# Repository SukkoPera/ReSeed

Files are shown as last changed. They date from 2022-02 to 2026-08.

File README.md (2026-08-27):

# ReSeed





ReSeed is an expansion card for the Commodore 16 and Plus/4 computers that allows interfacing the computer with a [MOS 6581 or 8580 Sound Interface Device](https://en.wikipedia.org/wiki/MOS_Technology_6581), the chip that is used to deliver audio on the Commodore 64.

It is based on [a design by Solder of Synergy](https://plus4world.powweb.com/hardware/Solders_SID_Card).

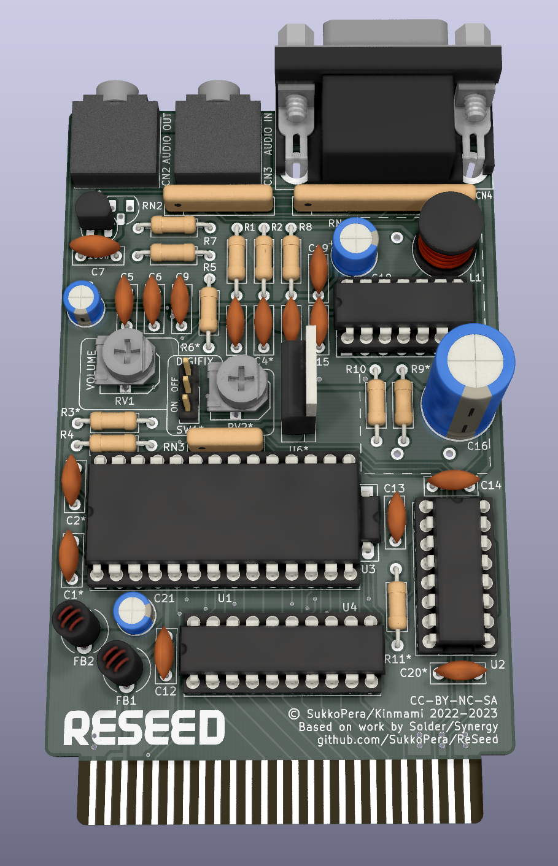
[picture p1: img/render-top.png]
Board


## Summary
Sounds from the C64 now for the Plus/4! Just plug the card into the Expansion Port! You can adjust the volume on the card. You can hear the sound over the Plus/4 audio or take it over a 3.5mm-Stereo-Cinch to a mixer or HiFi-Device. A 9-pin D-SUB connector allows connecting a 3<sup>rd</sup> (analog!) joystick or a proportional-mouse or (why not?) paddles!

*(Slight rewording of Solder's original description of the card.)*

## Design
ReSeed is derived from Solder's SIDcard, with a few enhancements.

### Modifications Introduced in V2
The focus for V2 was on reducing the output noise.

* New component values for the step-up voltage regulator: The values of some components were fine-tuned (again) in order to place the switching frequency of the step-up voltage converter way out of the audio band. These new values can also be retrofitted on a V1 board and will improve things dramatically (See [V1.1](https://github.com/SukkoPera/ReSeed/releases/tag/v1.1)).
* Alternative voltage step-up module: Cheap step-up voltage boost modules can now be used instead of the TL497-based circuit. Such modules, which can be easily sourced from Chinese portals, are much more modern and use a higher switching frequency, resulting in (near-)zero switching-induced noise. Using them also speeds up the assembly process, as many components can be skipped.
* Linear Regulator: If you are really paranoid about switching-induced noise, you can use the above alternatives as a first-stage voltage regulator and then make a second stage through a linear regulator, which should "eat" any remaining noise and provide the SID with very stable power.
* Separate grounds: A separate audio ground plane was introduced and connected to the signal ground plane through a single ferrite bead, preventing noise from spreading from the latter to the former. A second ferrite bead was inserted on the incoming +5V power rail in order to make it cleaner.
* Alternative BJT footprint: An alternative footprint for the output amplifier transistor was added, allowing for the mounting of the 2SC1815 BJT used in the original C64 audio circuit.
* SID clock delay circuit: This allows use of CD74HCT4520B chips in place of the CD4520B.
* Clock divider reset: Makes sure the SID clock always has the correct phase upon startup/reset.
* Short-circuit protection: In the original Solder design, a short-circuit can happen on the joystick port if it is written to. Series resistors were added in order to avoid this situation.

### Modifications Introduced in [V1](https://github.com/SukkoPera/ReSeed/releases/tag/v1)
* Supports both MOS 6581 and 8580 SIDs: this depends on mounting different components though, the board **cannot** be switched "on-the-fly", see [below](#Assembly).
* A volume control for the DigiFix was added and even a switch to completely bypass it.
* The output switch was removed: audio is automatically redirected to the Plus/4's EXT_AUDIO when nothing is connected to the output jack.
* The second stage of the amplifier was removed and the first stage modified so that it uses the same circuit and component values as the C64: the original card was known to introduce some distortion to the output signal as it was trying to amplify it, these days you can easily do better amplification outboard, so we chose to preserve sound fidelity.
* A decoupling capacitor was added close to every IC.
* The values for the step-up converter were recalculated in order to make the generated voltage less noisy and as ripple-free as possible.
* Last but not least, the design was documented and made open.

## Assembly
If you want to assemble a card, **please read the assembly notes on [the Wiki](https://github.com/SukkoPera/ReSeed/wiki) carefully or you might destroy your SID chip!**

### SID Replacements
Most SID replacements will not work correctly. This is because for technical reasons the clock that is provided to the SID has a lower frequency than what it gets on the C64 (~886 vs ~985 kHz). Most SID replacements do not use this clock signal at all and just assume C64 frequency (I guess), leading to incorrect data transfers. This is the case for the SwinSID firmware, for instance.  See below for a table of tested SID replacement devices.

| SID Device | Compatibility | Source | Notes |
|:---:|:---:|:---:|:---|
| [ARMSID](https://www.nobomi.cz/8bit/armsid/index_en.php) | Yes | [Root42](https://www.youtube.com/watch?v=OQfjMYeEfFY) | May have subtle incompatibility (detected during porting of config tool to +4), but unlikely to be seen in practise. |
| [SIDKick](https://github.com/frntc/SIDKick-pico) | In Progress | [SIDKick Pico Github](https://github.com/frntc/SIDKick-pico/discussions/36) | |
| [SwinSID](https://github.com/dmantione/swinsid) | No | SukkoPera | One report of compatibility, but no evidence provided. |
| BackSID | No | [BackBit Forums](https://forum.backbit.io/index.php?topic=1089.0) | Discontinued closed-source product; firmware unlikely to be patched. |
| [KungFuSID](https://github.com/Sgw32/KungFuSID) | No | SukkoPera |  |
| [PD-SID](https://uni64.com/shop/index.php?system=4&m=70&item_id=7536) | No | SteveGuidi | Firmware v191; no sound output and USB port inhibits proper seating in socket (obstructed by socketed CD74HCT4520E). |

## Games & Software
You can get images of the disks Solder used to ship with his SIDcard [here](https://plus4world.powweb.com/software/Synergy_Sidcard_Software). These will help making sure that the card works as intended.

[Here is also a list](https://plus4world.powweb.com/effects/SID_Support) of a lot of C16/+4 games and software supporting the card.

## Releases
If you want to get this board produced, you are recommended to get [the latest release](https://github.com/SukkoPera/ReSeed/releases) rather than the current git version, as the latter might be under development and is not guaranteed to be working.

Every release is accompanied by its Bill Of Materials (BOM) file and any relevant notes about it, which you are recommended to read carefully.

## Enclosure
A 3D-printable enclosure is currently available for this board, it was kindly contributed by [Starquake](https://www.forum64.de/wcf/index.php?user/17096-starquake/) and it is available in the [enclosure](./enclosure) folder.

Usage should be self-explanatory, just note that there are two slightly different versions depending on the SID model, as the one for the 8580 has an extra hole in the upper shell for the Digifix). You will probably have to bend the ferrites and capacitor at the bottom of the board a little to the side.

2x countersunk head screws M3x5mm will be required for assembly.

Please see [this thread on Forum64](https://www.forum64.de/index.php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) for more information and printing recommendations.

[SteveGuidi](https://github.com/SteveGuidi) kindly contributed original-264-style labels for the completed cartridge.

## License
The ReSeed documentation, including the design itself, is copyright &copy; SukkoPera 2022-2023 and is licensed under the [Creative Commons Attribution-NonCommercial-ShareAlike 4.0 International License](https://creativecommons.org/licenses/by-nc-sa/4.0/).

This documentation is distributed *as is* and WITHOUT ANY EXPRESS OR IMPLIED WARRANTIES whatsoever with respect to its functionality, operability or use, including, without limitation, any implied warranties OF MERCHANTABILITY, SATISFACTORY QUALITY, FITNESS FOR A PARTICULAR PURPOSE or infringement. We expressly disclaim any liability whatsoever for any direct, indirect, consequential, incidental or special damages, including, without limitation, lost revenues, lost profits, losses resulting from business interruption or loss of data, regardless of the form of action or legal theory under which the liability may be asserted, even if advised of the possibility or likelihood of such damages.

## Support the Project
If you want to get some boards manufactured, you can get them from PCBWay through this link:

PCB from PCBWay (https://www.pcbway.com/project/shareproject/ReSeed_v2_SIDcard_for_the_Commodore_16_Plus_4_32f442ec.html)

You get my gratitude and cheap, professionally-made and good quality PCBs, I get some credit that will help with this and [other projects](https://www.pcbway.com/project/member/shareproject/?bmbid=41100). You won't even have to worry about the various PCB options, it's all pre-configured for you!

Also, if you still have to register, [you can use this link](https://www.pcbway.com/setinvite.aspx?inviteid=41100) to get some bonus initial credit (and yield me some more).

You can also buy me a coffee if you want:



## Thanks
- Solder, for designing the original card and sharing its schematics.
- [Kinmami](https://github.com/kinmami) for his invaluable support
- Luca, Chronos and all the folks at [Plus/4 World](https://plus4world.powweb.com/forum) for helping with the troubleshooting
- [thireo](https://github.com/thireo) for the [3D model of the headphone jack](https://github.com/thireo/kicad-library)

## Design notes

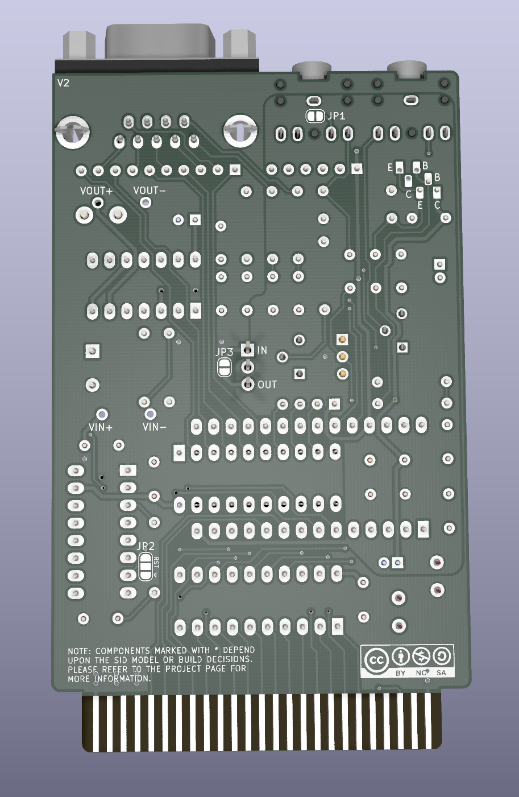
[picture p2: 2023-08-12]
img/render-bottom.png

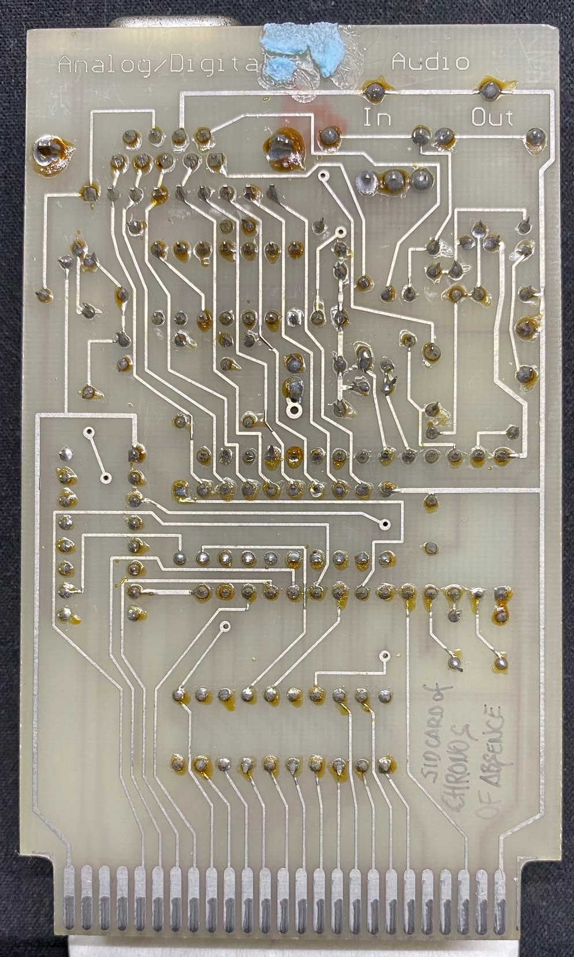
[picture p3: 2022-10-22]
doc/sidcard_chronos_bottom.jpg

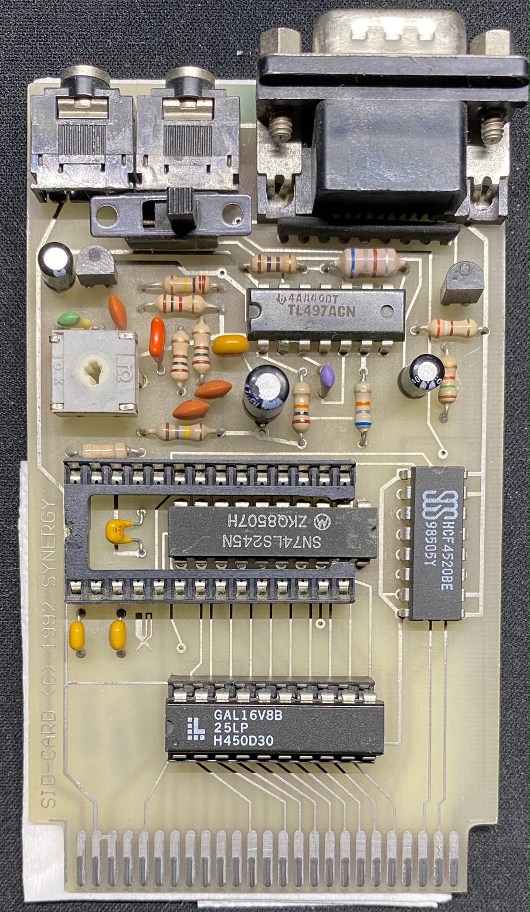
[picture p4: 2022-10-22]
doc/sidcard_chronos_top.jpg

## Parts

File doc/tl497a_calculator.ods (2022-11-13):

Pre-Regulator |  |  |  |  |  |  | Post-Regulator
 | IOMAX (A) | VO Pre (V) | VIN (V) | ton (µs) | Vripple(PK) Vpp | R2 (KΩ) |  | VO Post (V) | Power (W)
TL497A | 0.089 | 14.0 | 5.0 | 11 | 0.003 | 1.2 | 7809 (https://tinyurl.com/4sb5duz7) | 9.0 | 0.5 | No heatsink needed <1W
 |  | 13.9 |  |  | 1mVpp | 1.2 | 7812 (https://tinyurl.com/252ks9af) | 12.0 | 0.2 | No heatsink needed <1W
 | IPK (A) | L (µH) | CT (pF) | R1 (KΩ) | RCL (Ω) | CO Pre (µF)
 | 0.499 | 110.2292769 | 132 | 12.8 | 4.700 | 980.1
 |  | 100 | 130 | 12.7 | 4.7 | 1000
 |  |  |  | f (KHz) | Power (W) | Rated voltage (V)
 |  |  |  | 45.45454545 | 1.17 | 20.85
 |  |  |  |  |  |  |  |  |  | Pre-Regulator VI requires additional coupling capacitors:
 |  |  |  |  |  |  |  |  |  | 0.1µF ceramic
 |  |  |  |  |  |  |  |  |  | 100µF / 16V electrolytic
 |  |  |  |  |  |  |  |  |  | R1 and R2 are ±1%
 |  |  |  |  |  |  |  |  |  | CO Pre - Post are rated for 25V

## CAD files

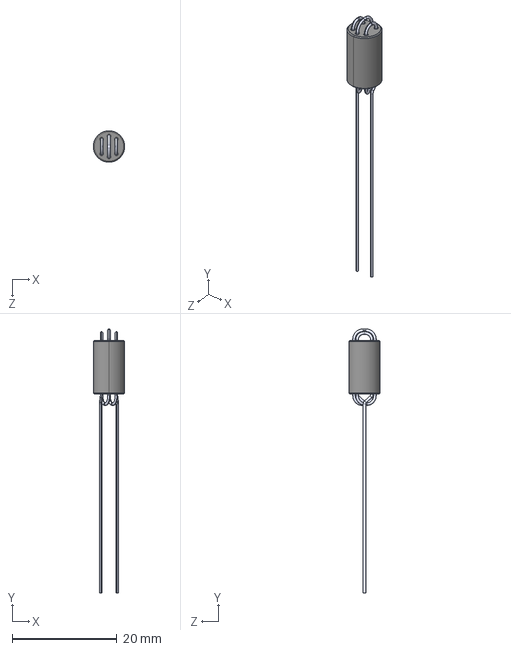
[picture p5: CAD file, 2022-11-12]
3dModels/28C0236-0EW-10--3DModel-STEP-460648.STEP
6.00 x 50.5 x 6.00 mm

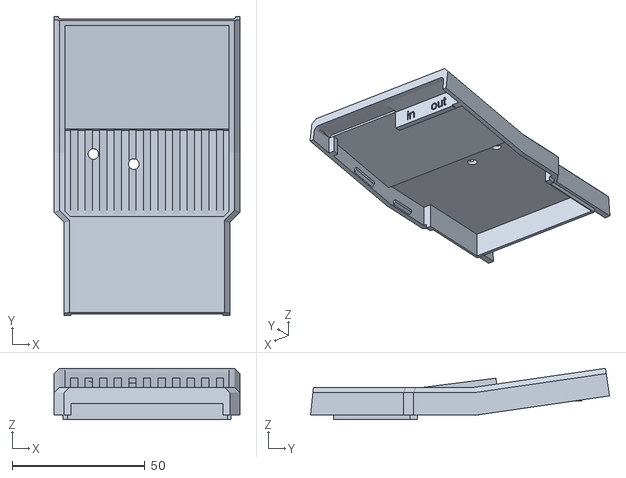
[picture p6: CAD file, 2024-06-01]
enclosure/ReSeed Case Lid 8580.stl
70.0 x 112.8 x 19.4

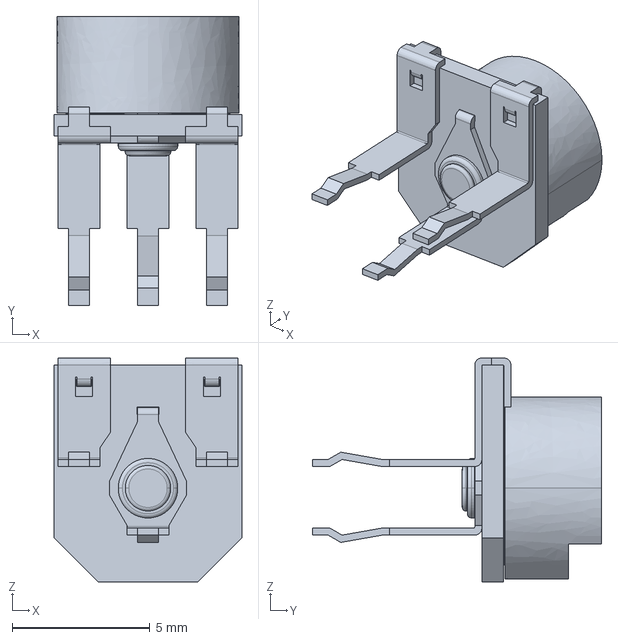
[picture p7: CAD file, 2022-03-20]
3dModels/3306p-1-101.stp
6.81 x 10.5 x 8.13 mm

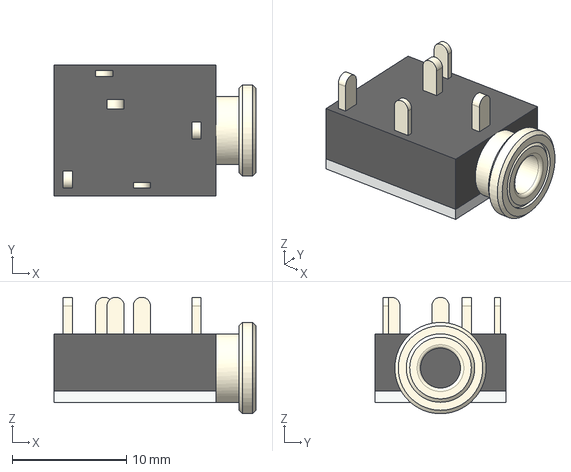
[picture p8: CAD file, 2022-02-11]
3dModels/EBS35 3.5mm Stereo Connector.stp
17.7 x 11.5 x 10.2 mm

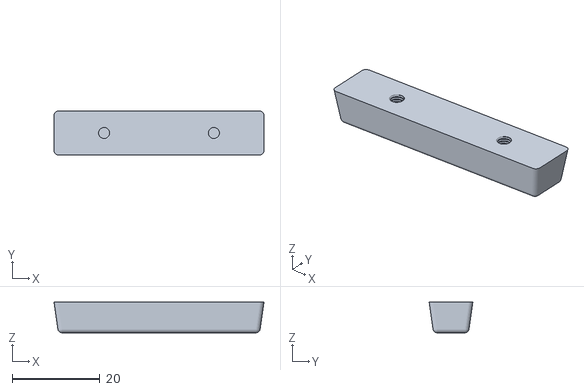
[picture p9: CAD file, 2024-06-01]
enclosure/ReSeed Case Base Spacer.stl
47.8 x 9.98 x 7.00

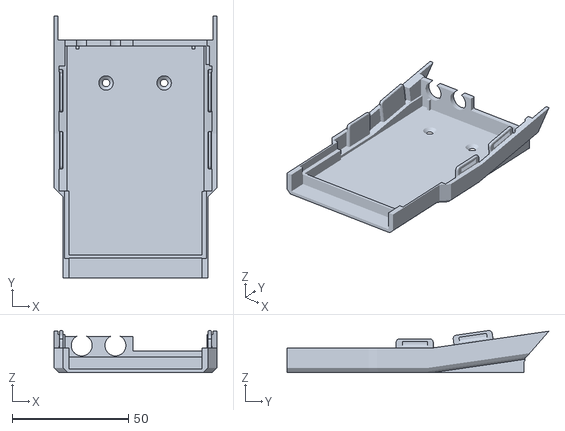
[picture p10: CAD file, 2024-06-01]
enclosure/ReSeed Case Base.stl
70.0 x 112.8 x 18.1

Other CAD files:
enclosure/ReSeed Case Lid 6581 straith.stl
enclosure/ReSeed Case Lid 6581.stl
enclosure/ReSeed Case Lid 8580 straith.stl

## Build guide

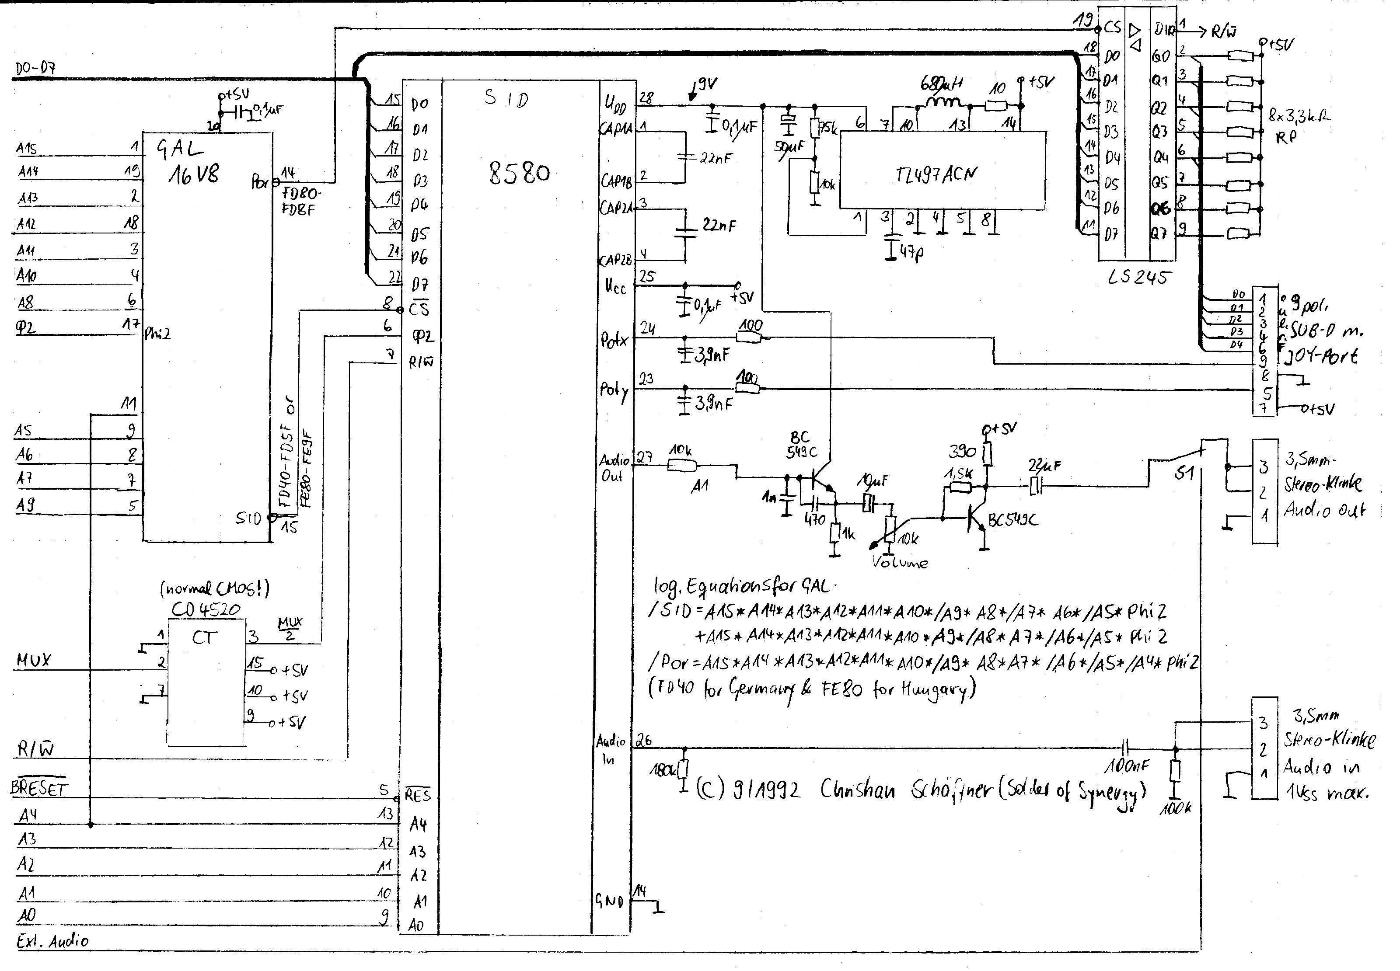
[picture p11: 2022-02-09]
doc/solders_sidcard.gif

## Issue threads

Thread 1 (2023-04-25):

Discrepancies within the generated BOM

kotbehemot53, 2023-04-25:
Hello,
I noticed that there are some discrepancies in the generated BOM, between the Mouser product numbers and corresponding component values:

L1: 652-RLB0914-331KL - the code refers to a 330 uH inductor, yet the component value is 100 uH, which would be 652-RLB0914-101KL;

C15: 810-FG28C0G1H470JNT0 - the code refers to a 47pF capacitor, yet the component value is 100pF which would be 810-FG28C0G1H101JNT6;

Q1: 512-BC549CTA - the code refers to a BC549C BJT transistor, yet the component value is a BC547C BJT which would be 512-BC547CBU;

RN1: 652-4609X-1LF-4.7K - the code refers to a 4.7 kOhm resistor array, yet the component value is 3.3 kOhm, which would be 652-4609X-1LF-3.3K.

I am aware that some of these are interchangeable, but I still think that the product numbers given should match the component values in the table, because in its current state it causes confusion when ordering parts by their numbers and checking their values.

SukkoPera, 2023-04-25:
Thanks for the notice, this will be fixed soon with the release of V1.2 and V2.0.

root42, 2023-08-11:
Any idea when 2.0 will be released? Or can I use the git version? I want to order a minimal number of boards so I can build 1 or 2 SID cards for my C16 and Plus/4 and ask on Forum64 if anyone else wants a board. Or in other words: is it worth waiting for 2.0?

SukkoPera, 2023-08-11:
I just need to find the time to prepare the docs and do the proper release, but the PCB you can find on the _devel_ branch is final. I will try in the weekend.

SukkoPera, 2023-08-12:
[V2](https://github.com/SukkoPera/ReSeed/releases/tag/v2) has been released, this should fix all of the inconsistencies.

I have decided not to make a v1.2, so I put a link to this issue in the v1.1 release. Let me precise that:

> L1: 652-RLB0914-331KL - the code refers to a 330 uH inductor, yet the component value is 100 uH, which would be 652-RLB0914-101KL;

Correct value is 100 uH.

> C15: 810-FG28C0G1H470JNT0 - the code refers to a 47pF capacitor, yet the component value is 100pF which would be 810-FG28C0G1H101JNT6;

Correct value is 100 pF.

> Q1: 512-BC549CTA - the code refers to a BC549C BJT transistor, yet the component value is a BC547C BJT which would be 512-BC547CBU;

Both can be used. BC549C is recommended as it is the low-noise version, but 547 (and 548, for the record) will work, too.

> RN1: 652-4609X-1LF-4.7K - the code refers to a 4.7 kOhm resistor array, yet the component value is 3.3 kOhm, which would be 652-4609X-1LF-3.3K.

Both will work. I recommend 4.7k because it's the value I tested but no worries ;).

@root42 If you want my boards, send me an email. They are gold-plated and beveled.

Closed 2023-08-12.

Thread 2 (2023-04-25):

Expanding the readme with information on how to prepare the GAL chip

kotbehemot53, 2023-04-25:
While building my ReSeed, I noticed that there was no info about what the GAL chip is and that it needs to be programmed before use. It might be obvious to some people, but not necessarily to every hobbyist. Therefore, I suggest adding a paragraph in the readme with some basic information.

I wanted to create my own branch and make a PR, but I didn't have sufficient permissions, so I'll paste my suggested paragraph here:

```
#### Programming U4 (the GAL chip)

U4 is a Programmable Logic Device or PLD, which means that it is not enough to just connect it to the board - it has to be programmed before use. The necessary .jed file storing the GAL's configuration is provided in the sources in the `gal` directory. To program the chip with the configuration provided, you need to use a programmer. You can build one yourself thanks to the `afterburner` project: https://github.com/ole00/afterburner. There is a simpler variant of the afterburner device (https://github.com/ole00/afterburner/tree/version_4_legacy) which is sufficient and can easily be built on a breadbord. A tutorial on how to do this is available here: https://www.instructables.com/Make-Your-Own-Microchips/.
```

I suggest adding the above paragraph as part of the `Integrated circuits` section.

SukkoPera, 2023-04-30:
I decided to move the assembly instructions to the Wiki and, while doing that, I integrated your suggestion. Please check if it is clearer now: https://github.com/SukkoPera/ReSeed/wiki/V1.x-Assembly-Notes.

kotbehemot53, 2023-05-01:
Looks great, cheers!

Closed 2023-05-01.

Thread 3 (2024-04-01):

R3 ambiguity between V2 assembly notes and BOM notes

SteveGuidi, 2024-04-01:
In the [V2 assembly notes](https://github.com/SukkoPera/ReSeed/wiki/V2-Assembly-Notes), we are directed to not mount R3 for an 8580 build.  However, the [notes in the BOM](https://github.com/SukkoPera/ReSeed/releases/download/v2/ReSeed-2-ibom.html) state that we should not mount R3 for a 6581 build.

SukkoPera, 2024-04-01:
I am under the impression I have already fixed this, but anyway the assembly notes are correct.

No big deal in any case, just a decrease in output volume.

SukkoPera, 2024-04-06:
BOM on release page updated.

Closed 2024-04-06.

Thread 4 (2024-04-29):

Please consider updating player program listing in wiki

SteveGuidi, 2024-04-29:
The player program listing from the "[Anleitung zur SID‐Karte](https://github.com/SukkoPera/ReSeed/wiki/Anleitung-zur-SID%E2%80%90Karte)" wiki page has a couple of problems:

- Memory addresses for op codes bytes and assembly instruction are ambiguous ([Interrupt-Routine](https://github.com/SukkoPera/ReSeed/wiki/Anleitung-zur-SID%E2%80%90Karte#interrupt-routine))

```assembly
. 3038  20 cd cd  jsr $cecd   ;TED-Sound bearbeiten
. 303b  4c be fc  jmp $fcc3   ;Interrupt beenden (2)
```

The correct address is the one listed in the assembly instruction, not the op code.  Note: The [original PDF documentation](https://plus4world.powweb.com/images/hardware/sidcard_manual.pdf) for the SidCard project has the same error.

- Missing `Y` register for memory offset in the `STA` instruction ([Musik Beenden](https://github.com/SukkoPera/ReSeed/wiki/Anleitung-zur-SID%E2%80%90Karte#musik-beenden))

```assembly
. 3084  99 40 fd  sta $fd40,  ;...löschen =
```

This should read `sta $fd40,y`

Finally, the player program distributed with the SidCard d64 disks is slightly different and corrects a couple of music play/stop issues.  Perhaps you can add it to the wiki, or note that code on the current page is a copy of the original documentation (with errors) and has since been updated.

Here is a listing of the updated player subroutines:

Music initialization

```assembly
. 3000 a9 00     lda #$00
. 3002 78        sei
. 3003 8d 3f ff  sta $ff3f
. 3006 20 00 10  jsr $1000
. 3009 a9 18     lda #$18
. 300b a0 30     ldy #$30
. 300d 8d 14 03  sta $0314
. 3010 8c 15 03  sty $0315
. 3013 8d 3e ff  sta $ff3e
. 3016 58        cli
. 3017 60        rts
```

Interrupt routine (music playback)

```assembly
. 3018 ad 09 ff  lda $ff09
. 301b 8d 09 ff  sta $ff09
. 301e 8d 3f ff  sta $ff3f
. 3021 20 03 10  jsr $1003
. 3024 a0 18     ldy #$18
. 3026 b9 00 d4  lda $d400,y
. 3029 99 40 fd  sta $fd40,y
. 302c 88        dey
. 302d 10 f7     bpl $3026
. 302f 8d 3e ff  sta $ff3e
. 3032 20 bf cf  jsr $cfbf
. 3035 20 cd ce  jsr $cecd
. 3038 20 11 db  jsr $db11
. 303b 4c be fc  jmp $fcbe
```

Stop playback

```assembly
. 3070 78        sei
. 3071 a9 0e     lda #$0e
. 3073 a0 ce     ldy #$ce
. 3075 8d 14 03  sta $0314
. 3078 8c 15 03  sty $0315
. 307b 58        cli
. 307c a0 18     ldy #$18
. 307e a9 00     lda #$00
. 3080 99 40 fd  sta $fd40,y
. 3083 88        dey
. 3084 10 fa     bpl $3080
. 3086 60        rts
```

SukkoPera, 2024-04-30:
Hi @SteveGuidi, thanks a lot for your corrections! I have removed editing restrictions from the wiki, could you please apply the modificiations yourself? I'm afraid I would still miss something!

This was still a work in progress BTW, when I have time I would like to translate the docs to English, but I guess it'd be better to do that once everything looks correct!

SteveGuidi, 2024-04-30:
Wiki changes committed: https://github.com/SukkoPera/ReSeed/wiki/Anleitung-zur-SID%E2%80%90Karte/_history.

SukkoPera, 2024-05-01:
Great job, thanks a lot!

Closed 2024-04-30.

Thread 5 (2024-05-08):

Techniques for improving TED pass-through volume

SteveGuidi, 2024-05-08:
This isn't an issue but more of a question or discussion topic.

I noticed that music playback through the TED generally has low volume (i.e. no speakers hooked up to the card's audio-out port).  I have a feeling that this is normal, but I wanted to confirm.  Note that if I maximize the volume via the volume resistor, I get marginal volume increase via the TED, but get a much larger gain through audio-out.

I suppose I could use a higher-gain transistor for the amplifier -- I'm using a 2N3904 with typical hFE of 100 @10mA.  (I got lazy here and just used this BJT as I have several on hand -- I didn't see that the recommended transistors have a higher gain!)  That said, does the transistor amplify the TED pass-through signal too?

SukkoPera, 2024-05-08:
First of all, the playback does not happen "through the TED" (I mean the TED chip). Rather, the SID output fed back into the machine through the EXT_AUDIO pin of the Expansion connector gets **mixed** with the TED audio output. This can be seen clearly from [the C16 schematics](https://github.com/SukkoPera/LittleSixteen/blob/master/output/schematics.pdf).

Second: yes, the volume control on the ReSeed board affects both the jack output and the signal that is fed back into the machine.

That said, I generally set it at about 90% of full range and I don't feel the volume is low at all. I have never tested the 2N3904 transistor though, all my boards have a BC547 or a 2SC1815. I see that the 2N3904 has an EBC pinout, so it looks like it should be installed **in the bottom footprint of Q1 but with the opposite orientation** (i.e. flat side towards the top of the board), did you install it like that?

If it's still low, I don't think it is necessary to use a transistor with a higher gain, it could be enough to play with the values of R4 and R5 to change the gain, even though I'm not exactly sure how :).

As a side note, the original SIDcard design from Solder had a 2-stage output amplifier circuit but it was often criticized for distorting the sound. We assumed it was mostly meant for driving passive external speakers, since our testing showed that the output volume through the EXT_AUDIO pin was already sufficient even without the 2nd stage. Since today it's much more common to have powered speakers, we decided to remove the 2nd stage, falling back to the original C64 circuit (plus volume control). But all of this means we went through quite some testing of the audio levels :).

SteveGuidi, 2024-06-25:
Thank you for the feedback, @SukkoPera.  The more I experiment with this, the more confident I get that thus is an issue with the factory single swipe TED socket.  I have an issue where if I tap or bump my C16, then the video shuts off temporarily or the machine crashes.  it does happen all the time, but I've found that I can get the mixed audio to drop in volume precisely when these video issues happen.

I'm pretty sure there is nothing wrong with the SID card or any of thr components installed on it, so the next step will be to replace the TED socket.

SukkoPera, 2024-06-25:
Well, that could justify if TED audio has low volume, but it shouldn't affect the audio coming from the SID.

Closed 2024-06-25.

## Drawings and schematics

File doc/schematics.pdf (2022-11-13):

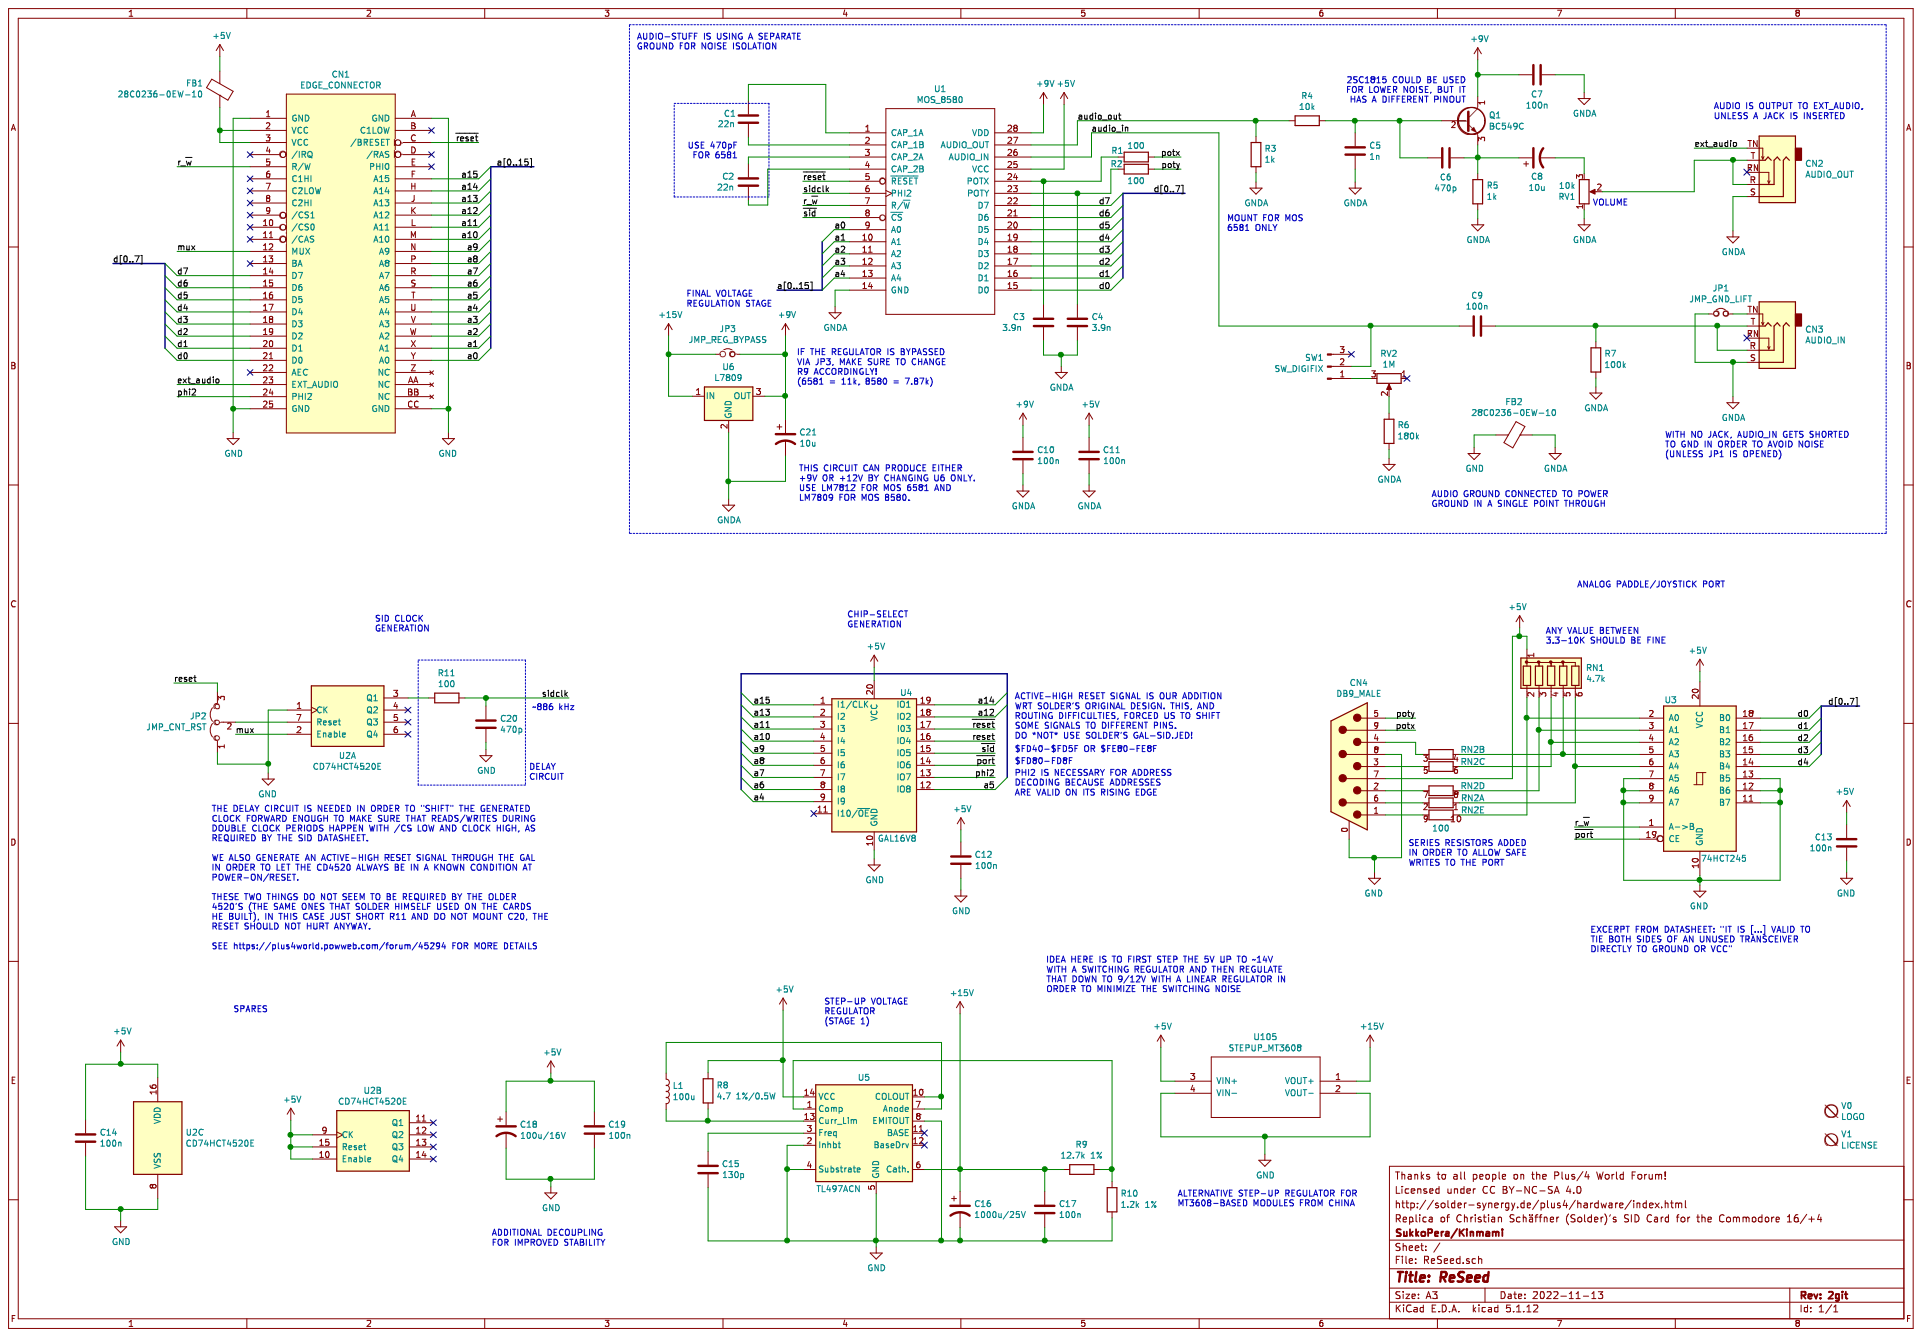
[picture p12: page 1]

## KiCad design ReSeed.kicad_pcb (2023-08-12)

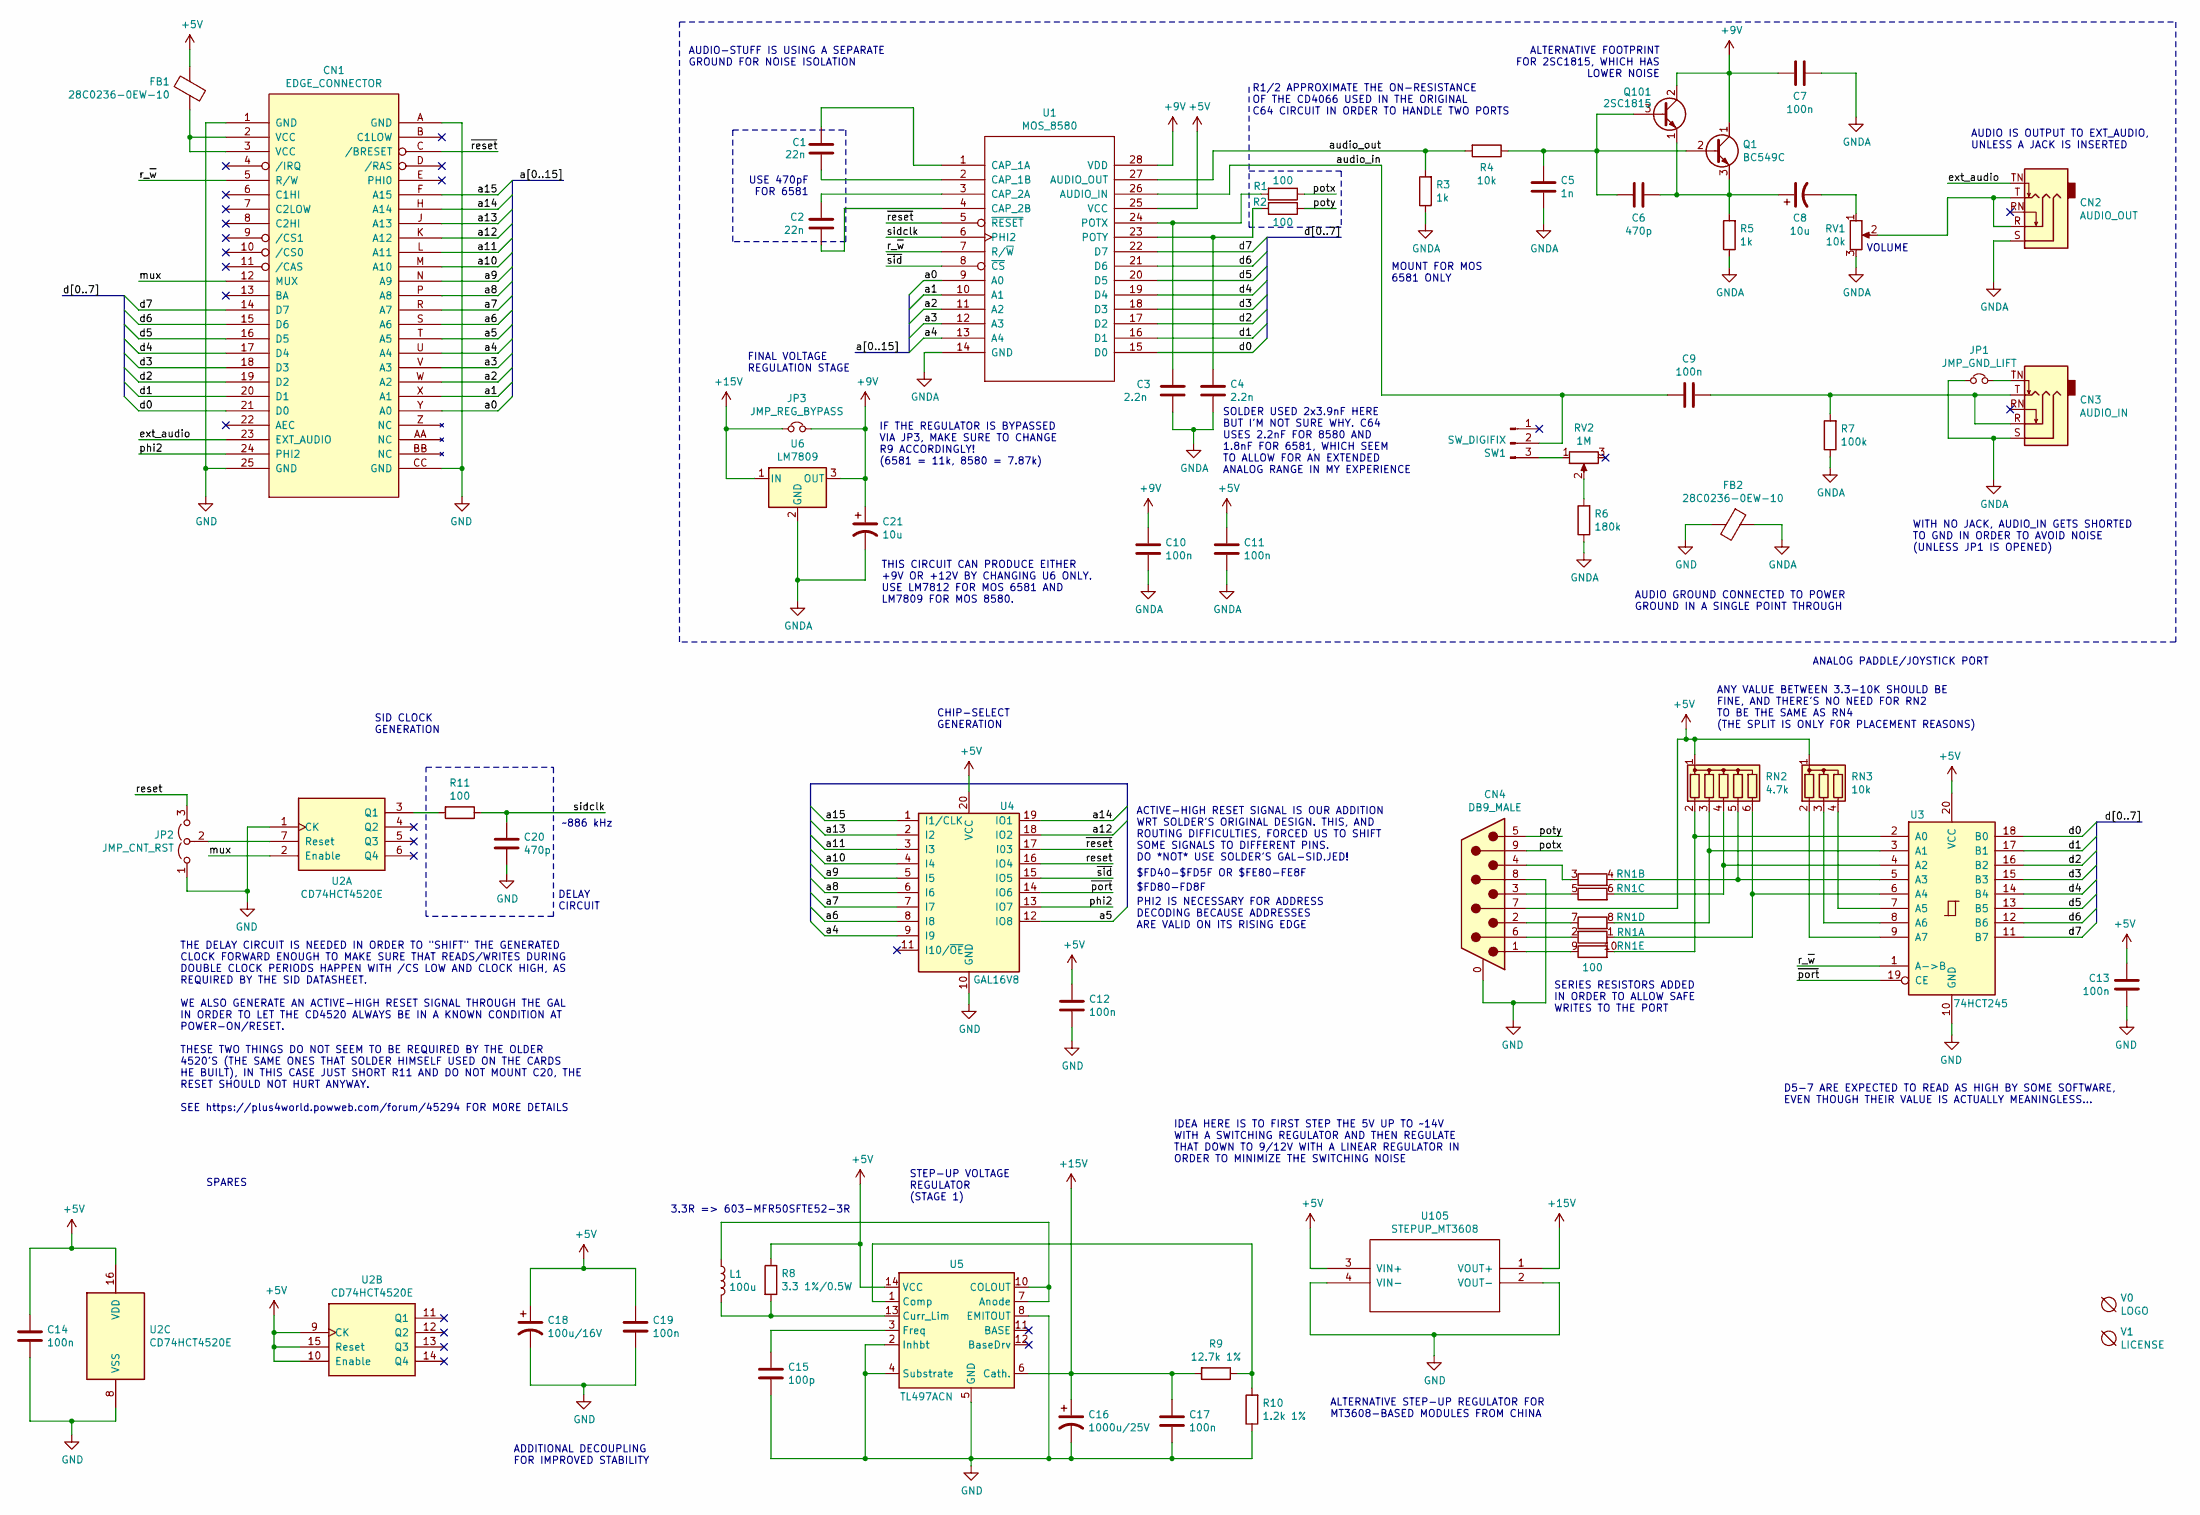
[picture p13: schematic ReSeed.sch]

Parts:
C1, C2: 22n; C_Disc_D7.0mm_W2.5mm_P5.00mm; MouserPN 810-FG28X7R1H223KNT0
C3, C4: 2.2n; C_Disc_D7.0mm_W2.5mm_P5.00mm; MouserPN 810-FG28C0G1H222JNT6
C5: 1n; C_Disc_D7.0mm_W2.5mm_P5.00mm; MouserPN 810-FG28C0G1H102JNT6
C6, C20: 470p; C_Disc_D7.0mm_W2.5mm_P5.00mm; MouserPN 810-FG28C0G1H471JNT6
C7, C9, C10, C11, C12, C13, C14, C17, C19: 100n; C_Disc_D7.0mm_W2.5mm_P5.00mm; MouserPN 810-FG28X7R1H104KNT0
C8, C21: 10u; CP_Radial_D5.0mm_P2.00mm; MouserPN 710-860010472002
C15: 100p; C_Disc_D7.0mm_W2.5mm_P5.00mm; MouserPN 810-FG28C0G1H101JNT6
C16: 1000u/25V; CP_Radial_D10.0mm_P5.00mm; MouserPN 710-860020475018
C18: 100u/16V; CP_Radial_D6.3mm_P2.50mm; MouserPN 710-860020573008
CN1: EDGE_CONNECTOR; C16_Cart_Conn; MouserPN ---
CN2: AUDIO_OUT; AudioJack_SJ1-3525N; MouserPN 490-SJ1-3525N
CN3: AUDIO_IN; AudioJack_SJ1-3525N; MouserPN 490-SJ1-3525N
CN4: DB9_MALE; DB_9M
FB1, FB2: 28C0236-0EW-10; L_Radial_D6.0mm_P4.00mm; MouserPN 875-28C0236-0EW-10
JP1: JMP_GND_LIFT; SolderJumper-2_P1.3mm_Bridged_RoundedPad1.0x1.5mm; MouserPN ---
JP2: JMP_CNT_RST; SolderJumper-3_P1.3mm_Open_RoundedPad1.0x1.5mm; MouserPN ---
JP3: JMP_REG_BYPASS; SolderJumper-2_P1.3mm_Open_RoundedPad1.0x1.5mm; MouserPN ---
L1: 100u; L_Radial_D8.7mm_P5.00mm_Fastron_07HCP; MouserPN 652-RLB0914-101KL
Q1: BC549C; TO-92_HandSolder; MouserPN 512-BC549CTA
Q101: 2SC1815; TO-92_HandSolder; MouserPN 610-2SC1815-GR
R1, R2, R11: 100; R_Axial_DIN0207_L6.3mm_D2.5mm_P10.16mm_Horizontal; MouserPN 660-MF1/4LCT52R101G
R3, R5: 1k; R_Axial_DIN0207_L6.3mm_D2.5mm_P10.16mm_Horizontal; MouserPN 603-MFR-25FBF52-1K
R4: 10k; R_Axial_DIN0207_L6.3mm_D2.5mm_P10.16mm_Horizontal; MouserPN 603-MFR-25FTF52-10K
R6: 180k; R_Axial_DIN0207_L6.3mm_D2.5mm_P10.16mm_Horizontal; MouserPN 603-MF0207FTE52-180K
R7: 100k; R_Axial_DIN0207_L6.3mm_D2.5mm_P10.16mm_Horizontal; MouserPN 603-MFR-25FBF52-100K
R8: 3.3 1%/0.5W; R_Axial_DIN0207_L6.3mm_D2.5mm_P10.16mm_Horizontal; MouserPN 603-MFR50SFTE52-3R3
R9: 12.7k 1%; R_Axial_DIN0207_L6.3mm_D2.5mm_P10.16mm_Horizontal; MouserPN 603-MFR-25FRF52-12K7
R10: 1.2k 1%; R_Axial_DIN0207_L6.3mm_D2.5mm_P10.16mm_Horizontal; MouserPN 603-MF0207FTE52-1K2
RN1: 100; R_Array_SIP10; MouserPN 652-4610X-2LF-100
RN2: 4.7k; R_Array_SIP6; MouserPN 652-4606X-1LF-4.7K
RN3: 10k; R_Array_SIP4; MouserPN 652-4604X-1LF-10K
RV1: 10k; Pot_Bourns_3306P; MouserPN 652-3306P-1-103
RV2: 1M; Pot_Bourns_3306P; MouserPN 652-3306P-1-105
SW1: SW_DIGIFIX; PinHeader_1x03_P2.54mm_Vertical
U1: MOS_8580; DIP-28_W15.24mm_Socket_LongPads; MouserPN :)
U2: CD74HCT4520E; DIP-16_W7.62mm_Socket_LongPads; MouserPN 595-CD74HCT4520E
U3: 74HCT245; DIP-20_W7.62mm_Socket_LongPads; MouserPN 595-SN74HCT245N
U4: GAL16V8; DIP-20_W7.62mm_Socket_LongPads; MouserPN 556-AF16V8B15PU
U5: TL497ACN; DIP-14_W7.62mm_Socket_LongPads; MouserPN 595-TL497ACNE4
U6: LM7809; TO-220-3_Vertical_Round; MouserPN 926-LM2940T-90/NOPB
U105: STEPUP_MT3608; ChineseUpstepperMT3608Style
V0: LOGO; Logo; MouserPN ---
V1: LICENSE; cc_by_nc_sa; MouserPN ---

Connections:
+5V: C11.1, C12.1, C13.1, C14.1, C18.1, C19.1, CN4.7, FB1.2, R8.1, RN2.1 (common), RN3.1 (common), U1.25 (VCC), U2.9 (CK), U2.10 (Enable), U2.15 (Reset), U2.16 (VDD), U3.20 (VCC), U4.20 (VCC), U5.14 (VCC), U105.3 (VIN+)
+9V: C7.2, C10.1, C21.1, JP3.2, Q1.1 (C), Q101.2 (C), U1.28 (VDD), U6.3 (OUT)
+15V: C16.1, C17.1, JP3.1, R9.2, U5.6 (Cath.), U6.1 (IN), U105.1 (VOUT+)
/a0: CN1.Y (A0), U1.9 (A0)
/a1: CN1.X (A1), U1.10 (A1)
/a2: CN1.W (A2), U1.11 (A2)
/a3: CN1.V (A3), U1.12 (A3)
/a4: CN1.U (A4), U1.13 (A4), U4.9 (I9)
/a5: CN1.T (A5), U4.12 (IO8)
/a6: CN1.S (A6), U4.8 (I8)
/a7: CN1.R (A7), U4.7 (I7)
/a8: CN1.P (A8), U4.6 (I6)
/a9: CN1.N (A9), U4.5 (I5)
/a10: CN1.M (A10), U4.4 (I4)
/a11: CN1.L (A11), U4.3 (I3)
/a12: CN1.K (A12), U4.18 (IO2)
/a13: CN1.J (A13), U4.2 (I2)
/a14: CN1.H (A14), U4.19 (IO1)
/a15: CN1.F (A15), U4.1 (I1/CLK)
/audio_in: C9.2, SW1.2, U1.26 (AUDIO_IN)
/audio_out: R3.2, R4.2, U1.27 (AUDIO_OUT)
/d0: CN1.21 (D0), U1.15 (D0), U3.18 (B0)
/d1: CN1.20 (D1), U1.16 (D1), U3.17 (B1)
/d2: CN1.19 (D2), U1.17 (D2), U3.16 (B2)
/d3: CN1.18 (D3), U1.18 (D3), U3.15 (B3)
/d4: CN1.17 (D4), U1.19 (D4), U3.14 (B4)
/d5: CN1.16 (D5), U1.20 (D5), U3.13 (B5)
/d6: CN1.15 (D6), U1.21 (D6), U3.12 (B6)
/d7: CN1.14 (D7), U1.22 (D7), U3.11 (B7)
/ext_audio: CN1.23 (EXT_AUDIO), CN2.TN
/mux: CN1.12 (MUX), U2.2 (Enable)
/phi2: CN1.24 (PHI2), U4.13 (IO7)
/potx: CN4.9, R1.1
/poty: CN4.5, R2.1
/r_~w: CN1.5 (R/W), U1.7 (R/~W), U3.1 (A->B)
/reset: JP2.3 (B), U4.16 (IO4)
/sidclk: C20.1, R11.1, U1.6 (PHI2)
/~port: U3.19 (CE), U4.14 (IO6)
/~reset: CN1.C (/BRESET), U1.5 (~RESET), U4.17 (I03)
/~sid: U1.8 (~CS), U4.15 (IO5)
GND: C12.2, C13.2, C14.2, C15.2, C16.2, C17.2, C18.2, C19.2, C20.2, CN1.1 (GND), CN1.25 (GND), CN1.A (GND), CN1.CC (GND), CN4.0 (PAD), CN4.8, FB2.2, JP2.1 (A), R10.1, U2.1 (CK), U2.8 (VSS), U3.10 (GND), U4.10 (GND), U5.2 (Inhbt), U5.4 (Substrate), U5.5 (GND), U5.8 (EMITOUT), U105.2 (VOUT-), U105.4 (VIN-)
GNDA: C3.2, C4.2, C5.2, C7.1, C10.2, C11.2, C21.2, CN2.S, CN3.S, FB2.1, JP1.1, R3.1, R5.1, R6.1, R7.1, RV1.3, U1.14 (GND), U6.2 (GND)
unnamed: C1.1, U1.1 (CAP_1A)
unnamed: C1.2, U1.2 (CAP_1B)
unnamed: C2.1, U1.3 (CAP_2A)
unnamed: C2.2, U1.4 (CAP_2B)
unnamed: C3.1, R1.2, U1.24 (POTX)
unnamed: C4.1, R2.2, U1.23 (POTY)
unnamed: C5.1, C6.2, Q1.2 (B), Q101.3 (B), R4.1
unnamed: C6.1, C8.1, Q1.3 (E), Q101.1 (E), R5.2
unnamed: C8.2, RV1.1
unnamed: C9.1, CN3.R, CN3.T, R7.2
unnamed: C15.1, U5.3 (Freq)
unnamed: CN1.2 (VCC), CN1.3 (VCC), FB1.1
unnamed: CN2.R, CN2.T, RV1.2
unnamed: CN3.TN, JP1.2
unnamed: CN4.1, RN1.9 (R5.1)
unnamed: CN4.2, RN1.7 (R4.1)
unnamed: CN4.3, RN1.5 (R3.1)
unnamed: CN4.4, RN1.3 (R2.1)
unnamed: CN4.6, RN1.2 (R1.2)
unnamed: JP2.2 (C), U2.7 (Reset)
unnamed: L1.1, U5.7 (Anode), U5.10 (COLOUT)
unnamed: L1.2, R8.2, U5.13 (Curr_Lim)
unnamed: R6.2, RV2.2
unnamed: R9.1, R10.2, U5.1 (Comp)
unnamed: R11.2, U2.3 (Q1)
unnamed: RN1.1 (R1.1), RN2.6 (R5), U3.6 (A4)
unnamed: RN1.4 (R2.2), RN2.5 (R4), U3.5 (A3)
unnamed: RN1.6 (R3.2), RN2.4 (R3), U3.4 (A2)
unnamed: RN1.8 (R4.2), RN2.3 (R2), U3.3 (A1)
unnamed: RN1.10 (R5.2), RN2.2 (R1), U3.2 (A0)
unnamed: RN3.2 (R1), U3.9 (A7)
unnamed: RN3.3 (R2), U3.8 (A6)
unnamed: RN3.4 (R3), U3.7 (A5)
unnamed: RV2.1, SW1.3

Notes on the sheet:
STEP-UP VOLTAGE REGULATOR (STAGE 1)
ANALOG PADDLE/JOYSTICK PORT
VOLUME
SPARES
D5-7 ARE EXPECTED TO READ AS HIGH BY SOME SOFTWARE, EVEN THOUGH THEIR VALUE IS ACTUALLY MEANINGLESS...
ALTERNATIVE FOOTPRINT FOR 2SC1815, WHICH HAS LOWER NOISE
WITH NO JACK, AUDIO_IN GETS SHORTED TO GND IN ORDER TO AVOID NOISE (UNLESS JP1 IS OPENED)
USE 470pF FOR 6581
THIS CIRCUIT CAN PRODUCE EITHER +9V OR +12V BY CHANGING U6 ONLY. USE LM7812 FOR MOS 6581 AND LM7809 FOR MOS 8580.
ADDITIONAL DECOUPLING FOR IMPROVED STABILITY
AUDIO IS OUTPUT TO EXT_AUDIO, UNLESS A JACK IS INSERTED
MOUNT FOR MOS 6581 ONLY
SID CLOCK GENERATION
DELAY CIRCUIT
THE DELAY CIRCUIT IS NEEDED IN ORDER TO "SHIFT" THE GENERATED CLOCK FORWARD ENOUGH TO MAKE SURE THAT READS/WRITES DURING DOUBLE CLOCK PERIODS HAPPEN WITH /CS LOW AND CLOCK HIGH, AS REQUIRED BY THE SID DATASHEET. WE ALSO GENERATE AN ACTIVE-HIGH RESET SIGNAL THROUGH THE GAL IN ORDER TO LET THE CD4520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
~~886 kHz
SERIES RESISTORS ADDED IN ORDER TO ALLOW SAFE WRITES TO THE PORT
ACTIVE-HIGH RESET SIGNAL IS OUR ADDITION WRT SOLDER'S ORIGINAL DESIGN. THIS, AND ROUTING DIFFICULTIES, FORCED US TO SHIFT SOME SIGNALS TO DIFFERENT PINS. DO *NOT* USE SOLDER'S GAL-SID.JED!
PHI2 IS NECESSARY FOR ADDRESS DECODING BECAUSE ADDRESSES ARE VALID ON ITS RISING EDGE
$FD80-FD8F
$FD40-$FD5F OR $FE80-FE8F
CHIP-SELECT GENERATION
ALTERNATIVE STEP-UP REGULATOR FOR MT3608-BASED MODULES FROM CHINA
AUDIO-STUFF IS USING A SEPARATE GROUND FOR NOISE ISOLATION
AUDIO GROUND CONNECTED TO POWER GROUND IN A SINGLE POINT THROUGH
IDEA HERE IS TO FIRST STEP THE 5V UP TO ~~14V WITH A SWITCHING REGULATOR AND THEN REGULATE THAT DOWN TO 9/12V WITH A LINEAR REGULATOR IN ORDER TO MINIMIZE THE SWITCHING NOISE
FINAL VOLTAGE REGULATION STAGE
IF THE REGULATOR IS BYPASSED VIA JP3, MAKE SURE TO CHANGE R9 ACCORDINGLY! (6581 = 11k, 8580 = 7.87k)
ANY VALUE BETWEEN 3.3-10K SHOULD BE FINE, AND THERE'S NO NEED FOR RN2 TO BE THE SAME AS RN4 (THE SPLIT IS ONLY FOR PLACEMENT REASONS)
3.3R => 603-MFR50SFTE52-3R
SOLDER USED 2x3.9nF HERE BUT I'M NOT SURE WHY. C64 USES 2.2nF FOR 8580 AND 1.8nF FOR 6581, WHICH SEEM TO ALLOW FOR AN EXTENDED ANALOG RANGE IN MY EXPERIENCE
R1/2 APPROXIMATE THE ON-RESISTANCE OF THE CD4066 USED IN THE ORIGINAL C64 CIRCUIT IN ORDER TO HANDLE TWO PORTS

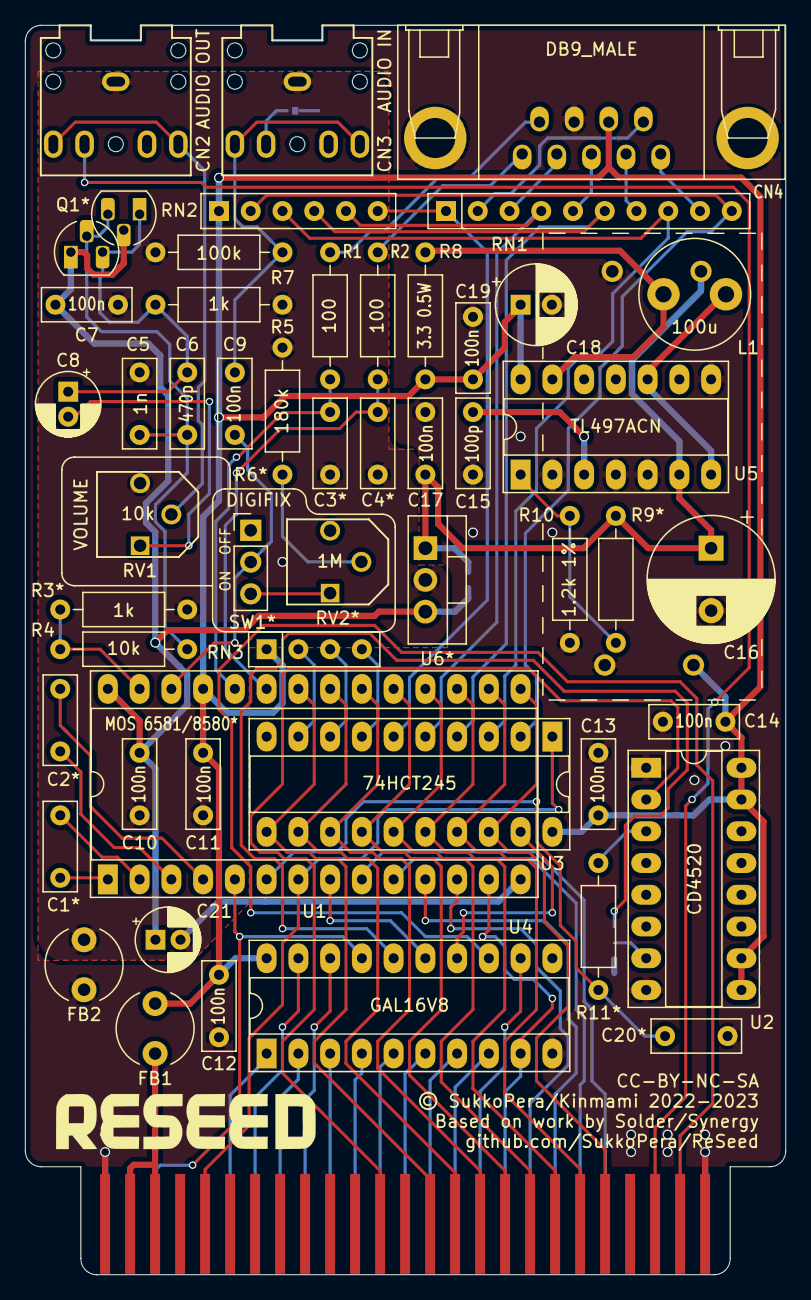
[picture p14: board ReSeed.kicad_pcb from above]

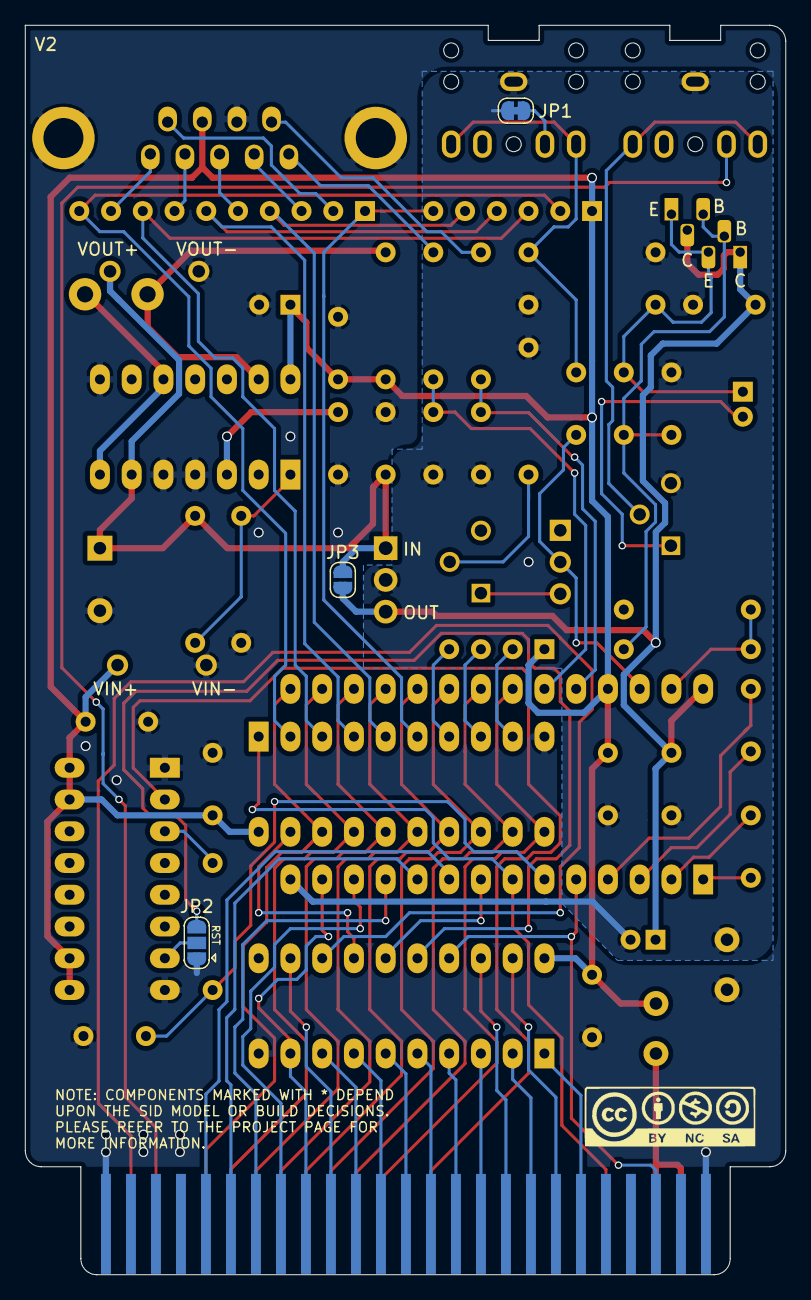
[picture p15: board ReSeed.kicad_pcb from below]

Board: 2 copper layers, 60.8 x 99.9 mm, 59 parts (4 on the bottom side), 76 nets.

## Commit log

2022-02-09 First commit Schematics and rough component placement complete
    [ReSeed.kicad_pcb, ReSeed.sch]
2022-02-10 Back side complete?
    [ReSeed.kicad_pcb, ReSeed.sch]
2022-02-11 Top routing in progress
    [ReSeed.kicad_pcb]
2022-02-11 Initial 1:1 replica complete
    [EBS35 3.5mm Stereo Connector.stp, ReSeed.kicad_pcb, ReSeed.sch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]
2022-02-12 Fix overlapping track
    [ReSeed.kicad_pcb]
2022-02-12 Switch to radial inductor and make boards slightly shorter
    [ReSeed.kicad_pcb, ReSeed.sch]
2022-02-12 Make board shorter than 10cm
    [ReSeed.kicad_pcb]
2022-02-12 Switch to ground plane and lots of improvements
    [ReSeed.kicad_pcb, ReSeed.sch]
2022-02-13 Tidy up silkscreen
    [ReSeed.kicad_pcb]
2022-02-13 Move some components around
    [ReSeed.kicad_pcb]
2022-02-16 Rework power circuit
    [ReSeed.kicad_pcb, ReSeed.sch]
2022-02-16 Add logo and license
    [ReSeed.kicad_pcb, ReSeed.sch]
2022-02-16 Work in progress
    [ReSeed.kicad_pcb, ReSeed.sch]
2022-02-16 Almost there...
    [ReSeed.kicad_pcb, ReSeed.sch]
2022-02-19 In Funken versunken
    [ReSeed.kicad_pcb]
2022-02-19 Stehe ich in Flammen
    [ReSeed.kicad_pcb]
2022-02-19 Und bin ich In Wasser verbrandt
    [ReSeed.kicad_pcb]
2022-02-20 Feuer und Wasser
    [ReSeed.kicad_pcb, ReSeed.sch]
2022-02-21 Add note about R3
    [ReSeed.kicad_pcb, ReSeed.sch]
2022-02-23 Improve decoupling on U5
    [ReSeed.kicad_pcb]
2022-03-05 Reroute some tracks around DC/DC converter
    [ReSeed.kicad_pcb]
2022-03-20 Reroute one more track to make ground more solid around DC-DC converter
    [ReSeed.kicad_pcb]
2022-03-20 Change headphone connectors
    [ReSeed.kicad_pcb, ReSeed.sch]
2022-03-20 Change pots
    [3306p-1-101.stp, ReSeed.kicad_pcb, ReSeed.sch]
2022-03-20 Fix silkscreen
    [ReSeed.kicad_pcb]
2022-10-24 Add clock delay circuit See https://plus4world.powweb.com/forum/45294 for more information
    [ReSeed.kicad_pcb, ReSeed.sch]
2022-10-24 Reset the 4520 with /RESET This required a lot of shuffling of the GAL pins.
    [ReSeed.kicad_pcb, ReSeed.sch]
2022-10-24 Add series resistors on joystick port
    [ReSeed.kicad_pcb, ReSeed.sch]
2022-10-24 Update GAL equations for V2 board
2022-10-24 Improve positioning of some tracks/components/labels
    [ReSeed.kicad_pcb, ReSeed.sch]
2022-10-24 Move some tracks
    [ReSeed.kicad_pcb]
2022-10-24 Fix BJT P/N
    [ReSeed.kicad_pcb, ReSeed.sch]
2022-10-24 Add renders and boards link
2022-11-06 WIP - Add footprint for MT3608-based regulator modules from China
    [ReSeed.kicad_pcb, ReSeed.sch]
2022-11-06 Routing completed - Need @kinmami's opinion on it
    [ReSeed.kicad_pcb]
2022-11-06 Move track
    [ReSeed.kicad_pcb]
2022-11-08 Make counter reset DISABLABLE
    [ReSeed.kicad_pcb, ReSeed.sch]
2022-11-11 Try separating signal and power grounds
    [ReSeed.kicad_pcb, ReSeed.sch]
2022-11-11 Only missing ferrites
    [ReSeed.kicad_pcb]
2022-11-12 Add ferrites on power lines
    [28C0236-0EW-10--3DModel-STEP-460648.STEP, ReSeed.kicad_pcb, ReSeed.sch]
2022-11-12 Use 2-stage step-up voltage regulation @kinmami: You owe me a monument
    [ReSeed.kicad_pcb, ReSeed.sch]
2022-11-12 Silkscreen fixes
    [ReSeed.kicad_pcb]
2022-11-12 Add bypass jumper for 2nd regulator stage
    [ReSeed.kicad_pcb, ReSeed.sch]
2022-11-12 Change 3D model of ferrites
    [ReSeed.kicad_pcb]
2022-11-12 Reverse pots so that volume grows clockwise
    [ReSeed.kicad_pcb, ReSeed.sch]
2022-11-12 R8 -> 4.7R, C16 -> 1000u This fixes a lot of the background noise!
    [ReSeed.kicad_pcb, ReSeed.sch]
2022-11-12 Fix track leading to LDO
    [ReSeed.kicad_pcb]
2022-11-12 Final touches on silkscreen
    [ReSeed.kicad_pcb]
2022-11-13 Update notes, P/Ns, schematics, docs, etc.
    [ReSeed.kicad_pcb, ReSeed.sch, tl497a_calculator.ods]
2022-11-13 Minor grounding improvements
    [ReSeed.kicad_pcb]
2022-12-08 Fix some part numbers
    [ReSeed.sch]
2022-12-09 Add alternative footprint for 2SC1815 transistor
    [ReSeed.kicad_pcb, ReSeed.sch]
2022-12-09 Undo pot reversal
    [ReSeed.kicad_pcb, ReSeed.sch]
2022-12-09 C15 -> 100pF
    [ReSeed.kicad_pcb, ReSeed.sch]
2022-12-09 Make Chinese step-up module pins closer
    [ReSeed.kicad_pcb]
2022-12-11 Correct P/Ns of resistor networks
    [ReSeed.sch]
2023-01-14 Correct BJT terminal labels Grrrrrrrrrrrrrrr!!!
    [ReSeed.kicad_pcb]
2023-01-14 R8 -> 3.3 ohm
    [ReSeed.kicad_pcb, ReSeed.sch]
2023-01-15 Make D5-7 high on joystick reads Solder's joyport tester seems to require this, sigh...
    [ReSeed.kicad_pcb, ReSeed.sch]
2023-01-15 Update copyright year
    [ReSeed.kicad_pcb]
2023-01-15 Add note on C3/4
    [ReSeed.sch]
2023-01-15 Reduce output noise C15 -> 100p, R8 -> 3.3, L1 -> 100u
    [ReSeed.kicad_pcb, ReSeed.sch]
2023-01-15 Add P/N for Q101
    [ReSeed.kicad_pcb, ReSeed.sch]
2023-01-15 Add P/Ns
    [ReSeed.kicad_pcb, ReSeed.sch]
2023-08-12 Make C3/4 SID-model-dependent
    [ReSeed.kicad_pcb, ReSeed.sch]
2023-08-12 BOM fixes for #1 and README update
    [ReSeed.kicad_pcb, ReSeed.sch]
2024-06-01 Fix confusion about R3 - See #3
    [ReSeed.sch]
2024-06-01 Add enclosure, thanks Starquake!
    [ReSeed Case Base Spacer.stl, ReSeed Case Base.stl, ReSeed Case Lid 6581 straith.stl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]
2025-06-05 Created cartridge labels for the enclosure in the style of existing 264-series cartridges
2026-04-22 Update README.md
    Added compatibility table for SID replacement devices.

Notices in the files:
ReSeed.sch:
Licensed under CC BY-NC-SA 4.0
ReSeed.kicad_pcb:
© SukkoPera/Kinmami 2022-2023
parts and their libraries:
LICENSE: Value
